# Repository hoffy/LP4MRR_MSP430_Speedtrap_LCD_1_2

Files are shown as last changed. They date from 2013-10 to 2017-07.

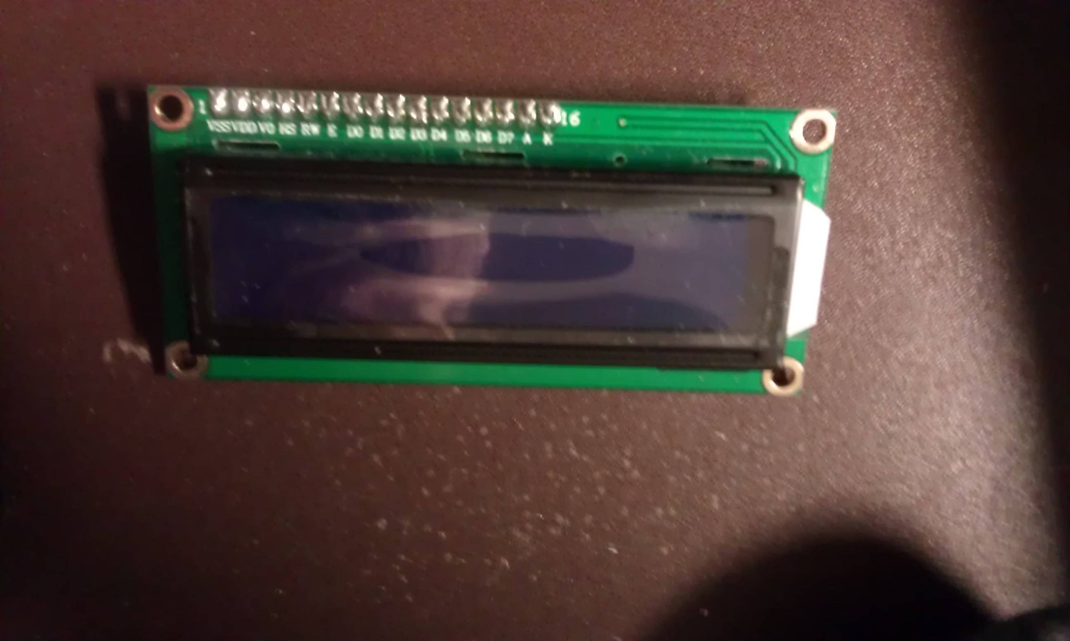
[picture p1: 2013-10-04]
1602A LCD Photo.jpg

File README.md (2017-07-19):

# LP4MRR_MSP430_Speedtrap_LCD_1_2
Code Composer Written Speed Trap with LCD for the Launchpads for Model Railroading Project

Please view the Layout Schematics & Instructions PDF

------------------------------------------------------
Revision History::

6/1/2015

I discovered recently while reviewing this repository that the schematic design had two serious "but not dangerous" issues that needed to
be corrected.  The pinout for the LCD was backwards, and a ground trace was missing on the schematic.  These issues have been resolved.
I have also included larger versions of the schematic and breadboard layouts in both PDF & PNG formats.  There is currently no Circuit
Board design associated with this project.  If anyone wishes to develop one that provides for the MSP430G2553 IC and a regulated 3.3
Volts & 5 Volt Supply as required for the circuit please by all means do so and share.  I'm all about fair attribution and open to
improvement ideas.
----------

6/5/2015

I discovered that the speed & counter variables were not clearing properly.  This was corrected by adding counter = 0 and speed = 0 to the
primary WHILE loop.  This error resulted in a miscalculation of the speed. The LCD code was also relocated to speed the processing of the
counter and reduce program lag time.
----------

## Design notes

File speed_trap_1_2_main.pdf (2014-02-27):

1 | /*
2 | * IR Beam Detected Speed Trap (Single Track Version) Version 1.2 LCD Edition
3 | *
4 | * Provided under a Creative Commons Attribution, Non-Commercial Share Alike,3.0 Unported
License
5 | *
6 | * COPYRIGHT 2013 - S.D. "Hoffy" Hofmeister, et al
7 | ********************************************************************************************
*****
8 | * CREDITS:
9 | *
10 | * Speed calculations & initial concept coding by: Toni Ryan
11 | *
12 | * IR Beam Detection & LCD Integration by: S.D. "Hoffy" Hofmeister
13 | *
14 | * LCD Library (lcdLib.h & lcdLib.c) The University of Texas at El Paso -
15 | * College of Engineering: http://www.ece.utep.edu/courses/web3376/Lab_5_-_LCD.html
16 | * Elliott Gurrola, Luis Carlos Bañuelos-Chacon, Elias N Jaquez
17 | *
18 | * This code is a group source project through The Launchpad for Model Railroading Project
19 | * - http://launchpad4mrr.blogspot.com/
20 | *
21 | ********************************************************************************************
******************
22 | * TARGETED TO MSP430 LANUCHPAD W/MSP430G2553 PROCESSOR
23 | *
24 | * Design Notes:
25 | *
26 | * This code is designed to to trigger a speed calculation for a model train passing
through 2 IR beam Sensors.
27 | * The code is designed to take a "speed reading" or "Time Count" in both directions.
28 | *
29 | * Distance between Tip of IR Emitter and Tip of Detector has only been tested up to 3.5
Inches under
30 | * incandescent and fluorescent lighting conditions with no failures.
31 | *
32 | * LCD Coding is designed for a QC1602A Ver 2.0 LCD Module
33 | *
34 | * Circuit Pinout:
35 | * PIN 1.0 = RED INDICATOR LED
36 | * PIN 1.1 = UNASSIGNED - UART
37 | * PIN 1.2 = UNASSIGNED - UART
38 | * PIN 1.3 = UNASSIGNED
39 | * PIN 1.4 = Cathode of IR Beam Receiver #1 | > Anode to Ground
40 | * PIN 1.5 = Cathode of IR Beam #2 | | > Anode to Ground
41 | * PIN 1.6 = GREEN INDICATOR LED
42 | * PIN 1.7 = UNASSIGNED
43 | * PIN 2.0 = LCD D4
44 | * PIN 2.1 = LCD D5
45 | * PIN 2.2 = LCD D6
46 | * PIN 2.3 = LCD D7
47 | * PIN 2.4 = E (Enable)
48 | * PIN 2.5 = RS (Register Signal)
49 | *
50 | * PINS 1.1, 1.2, 1.5, 1.7 are left open for integration into other projects
51 | *
52 | * Note Anodes for the IR Emitters connect to VCC and Cathodes to Ground
53 | */
54 | //******************************************************************************************
***********
55 | #include <msp430g2553.h>
56 | #include "lcdLib.h"
57 | // Declare functions
58 | void | | delay | | ( | | unsigned | | int | | ); | | // delay for xx 10ms increments
59 | // Declare variables
60 | float | | scale | | = | | 160; | | | | // denominator of scale (N scale 1:160)
61 | float | | gate | | = | | 12; | | | | // timing gate spacing (in inches)
62 | float | | speed | | = | | 0; | | // speed in MPH
63 | long | | unsigned | | int | | factor | | = | | 109090; | | | // number of ms to travel "gate" inches at 1 MPH for
"scale" scale (1 MPH slowest speed we can display)
64 | long | | unsigned | | int | | counter | | = | | 0; | | | // millisecond counter
65 | int | | counter_active | | = | | 0; | | | // flag to increment counters or stop counting
66 | int | | output_count | | = | | 0; | | | // flag to display time
67 | int | | lockgate_1 | | = | | 0; | | | // Locks Gate #1 from interrupting until unlocked
68 | int | | lockgate_2 | | = | | 0; | | | // Locks Gate #2 from interrupting until unlocked
69 | void | | main(void)
70 | {
71 | | WDTCTL | | = | | WDTPW | | + | | WDTHOLD; | | | // Stop WDT
72 | | BCSCTL1 | | = | | CALBC1_1MHZ; | | | // Set range
73 | | DCOCTL | | = | | CALDCO_1MHZ; | | | // Set DCO step + modulation
74 | | CCTL0 | | = | | CCIE; | | | // CCR0 interrupt enabled
75 | | TACTL | | = | | TASSEL_2 | | + | | MC_1 | | + | | ID_3; | // SMCLK/8, upmode
76 | | CCR0 | | = | | 125; | | | | | | | | | // 1000 Hz = 1 ms clock
77

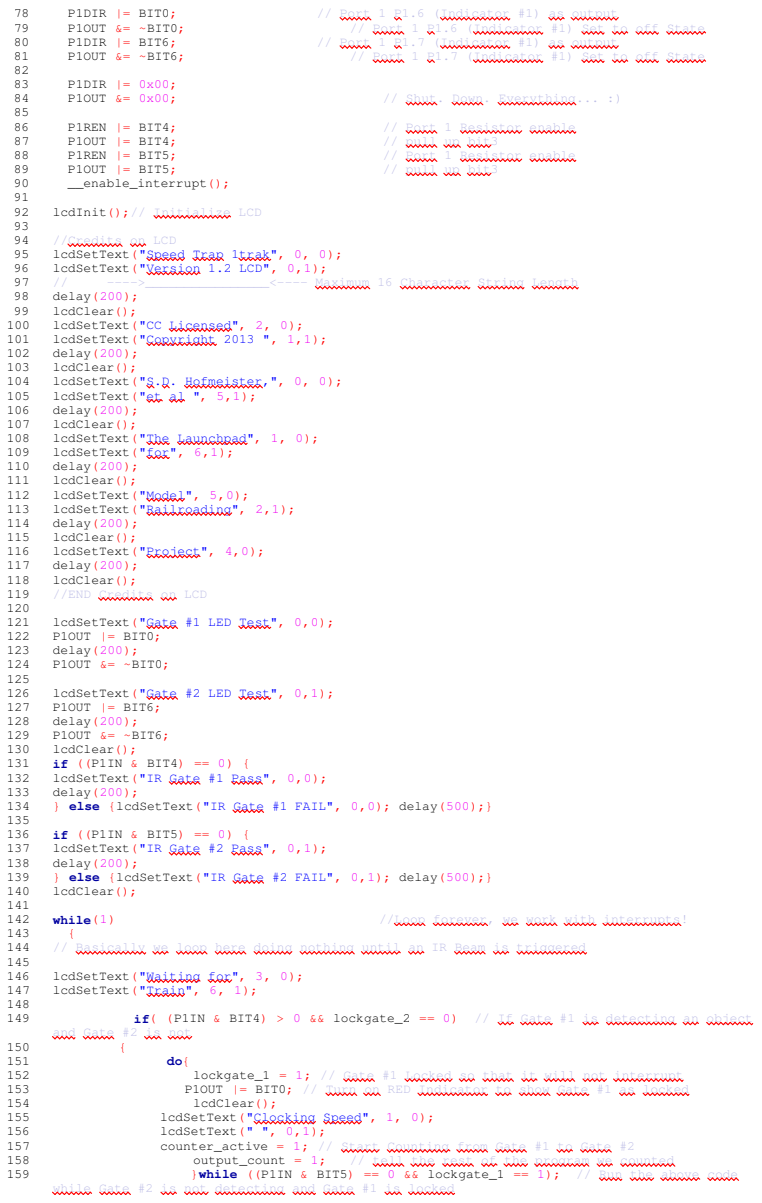
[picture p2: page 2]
P1DIR; BIT0;; // Port 1 P1.6 (Indicator #1) as output; ---->________________<---- Maximum 16 Character String Length

79 | | P1OUT | &= | ~BIT0; | | | | // Port 1 P1.6 (Indicator #1) Set to off State
80 | | P1DIR | |= | BIT6; | | | // Port 1 P1.7 (Indicator #1) as output
81 | | P1OUT | &= | ~BIT6; | | | | // Port 1 P1.7 (Indicator #1) Set to off State
82
83 | | P1DIR | |= | 0x00;
84 | | P1OUT | &= | 0x00; | | // Shut. Down. Everything... :)
85
86 | | P1REN | |= | BIT4; | | | | // Port 1 Resistor enable
87 | | P1OUT | |= | BIT4; | | | | // pull up bit3
88 | | P1REN | |= | BIT5; | | | | // Port 1 Resistor enable
89 | | P1OUT | |= | BIT5; | | | | // pull up bit3
90 | | __enable_interrupt();
91
92 | lcdInit();// Initialize LCD
93
94 | //Credits on LCD
95 | lcdSetText("Speed Trap 1trak", | | | 0, | 0);
96 | lcdSetText("Version 1.2 LCD", | | | 0,1);

98 | delay(200);
99 | lcdClear();
100 | lcdSetText("CC Licensed", | | | | | 2, | | | 0);
101 | lcdSetText("Copyright 2013 ", | | | | | 1,1);
102 | delay(200);
103 | lcdClear();
104 | lcdSetText("S.D. Hofmeister,", | | | | | 0, | | | 0);
105 | lcdSetText("et al ", | | | | | 5,1);
106 | delay(200);
107 | lcdClear();
108 | lcdSetText("The Launchpad", | | | | | 1, | | | 0);
109 | lcdSetText("for", | | | | | 6,1);
110 | delay(200);
111 | lcdClear();
112 | lcdSetText("Model", | | | | | 5,0);
113 | lcdSetText("Railroading", | | | | | 2,1);
114 | delay(200);
115 | lcdClear();
116 | lcdSetText("Project", | | | | | 4,0);
117 | delay(200);
118 | lcdClear();
119 | //END Credits on LCD
120
121 | lcdSetText("Gate #1 LED Test", | | | | | 0,0);
122 | P1OUT | | |= | | BIT0;
123 | delay(200);
124 | P1OUT | | &= | | ~BIT0;
125
126 | lcdSetText("Gate #2 LED Test", | | | | | 0,1);
127 | P1OUT | | |= | | BIT6;
128 | delay(200);
129 | P1OUT | | &= | | ~BIT6;
130 | lcdClear();
131 | if | | ((P1IN | | | & | | BIT4) | | | == | | 0) | | | {
132 | lcdSetText("IR Gate #1 Pass", | | | | | 0,0);
133 | delay(200);
134 | } | | else | | {lcdSetText("IR Gate #1 FAIL", | | | | | | 0,0); | | | | | delay(500);}
135
136 | if | | ((P1IN | | | & | | BIT5) | | | == | | 0) | | | {
137 | lcdSetText("IR Gate #2 Pass", | | | | | 0,1);
138 | delay(200);
139 | } | | else | | {lcdSetText("IR Gate #2 FAIL", | | | | | | 0,1); | | | | | delay(500);}
140 | lcdClear();
141
142 | while(1) | | | | | //Loop forever, we work with interrupts!
143 | | {
144 | // Basically we loop here doing nothing until an IR Beam is triggered
145
146 | lcdSetText("Waiting for", | | | | | 3, | | | 0);
147 | lcdSetText("Train", | | | | | 6, | | | 1);
148
149 | | | | if( | | | (P1IN | | | & | | BIT4) | | | > | | 0 | | && | | lockgate_2 | | == | | 0) | | // If Gate #1 is detecting an object

and Gate #2 is not

150 | | {
151 | | | | | do{
152 | | | | | | | lockgate_1 | | = | | 1; | | | // Gate #1 Locked so that it will not interrupt
153 | | | | | | P1OUT | | |= | | BIT0; | | | // Turn on RED Indicator to show Gate #1 as locked
154 | | | | | | | lcdClear();
155 | | | | lcdSetText("Clocking Speed", | | | | | 1, | | | 0);
156 | | | | lcdSetText(" ", | | | | | 0,1);
157 | | | | counter_active | | = | | 1; | | | // Start Counting from Gate #1 to Gate #2
158 | | | | | | | output_count | | = | | 1; | | | | // tell the rest of the program we counted
159 | | | | | }while | | | ((P1IN | | | & | | BIT5) | | | == | | 0 | | && | | lockgate_1 | | == | | 1); | | // Run the above code

while Gate #2 is not detecting and Gate #1 is locked

160 | } | else | {lockgate_1 | = | 0; | P1OUT | &= | ~BIT0;} | // Otherwise unlock Gate #1 and turn off
RED INDICATOR LED
161
162
163
164 | | if( | | | (P1IN | | | & | | BIT5) | | | > | | 0 | | && | | lockgate_1 | == | | 0 | ) | // If Gate #2 is detecting an object
and Gate #1 is not
165 | | {
166 | | | do | | {
167 | | | | lockgate_2 | | = | | 1; | | | // Gate #2 Locked so that it will not interrupt
168 | | | | P1OUT | | |= | | BIT6; | | | // Turn on GREEN Indicator to show Gate #2 as locked
169 | | | | lcdClear();
170 | | | | lcdSetText("Clocking Speed", | | | | | 1, | | | 0);
171 | | | | lcdSetText(" ", | | | | | 0,1);
172 | | | | counter_active | | = | | 1; | | | // Start Counting from Gate #2 to Gate #1
173 | | | | output_count | | = | | 1; | | | // tell the rest of the program we counted
174 | | | | }while | | | ((P1IN | | | & | | BIT4) | | | == | | 0 | | && | lockgate_2 | | == | 1); | | // Run the above code
while Gate #1 is not detecting and Gate #2 is locked
175
176 | | | }else | | | {lockgate_2 | | | = | | 0; | | | P1OUT | | &= | | ~BIT6;} | | | // Otherwise unlock Gate #2 and turn
off GREEN INDICATOR LED
177
178 | | counter_active | | = | | 0; | | | | // done counting - ready to output
179
180 | | | | if | | ( | | output_count | | == | | 1 | | ) | | { | | // show the count
181 | | | | | // calculate speed in MPH
182 | | | | | speed | | = | | factor | | / | | counter; | | | // calculate MPH
183 | | | | | lcdClear();
184 | | | | | lcdSetText("Train Speed", | | | | | 2, | | | 0);
185 | | | | | lcdSetInt(speed, | | | | | 4, | | | 1);
186 | | | | | lcdSetText("MPH", | | | | | 8,1);
187 | | | | | delay(500);
188 | | | | | output_count | | = | | 0; | | | // stop displaying and wait for another trigger
189 | | | | | lcdClear();
190
191 | | | } | | | // end of IF
192 | | } | | | // end of WHILE
193 | } | | | // end of MAIN
194
195 | // Timer A0 interrupt service routine
196 | #pragma vector=TIMER0_A0_VECTOR
197 | __interrupt | | void | | Timer_A | | (void)
198 | {
199 | | if | | (counter_active | | | == | | 1) | | | {
200 | | | counter | | = | | counter | | + | | 1; | | | | // just counting milliseconds
201
202 | | | if | | (counter | | | > | | factor) | | | { | | | // if our counter reaches factor, we're going less than
1 MPH
203 | | | | | | | | | | // and we can't display it, so ...
204 | | | | counter | | = | | 0; | | | | | | // zero counter
205 | | | | counter_active | | = | | 0; | | | | // stop counting
206 | | | | delay(1000); | | | | | | // and hang for a bit
207 | | | | }
208 | | }// then return to main
209 | }// end of TIMER_A interrupt handler
210
211 | // Port 1 interrupt service routine
212 | #pragma vector=PORT1_VECTOR
213 | __interrupt | | void | | Port_1(void)
214 | {
215 | | while | | (lockgate_1 | | | == | | 1) | | | { | | // Locks interrupt from disturbing opposite direction
| detection
216 | | | P1IFG | | &= | | ~BIT5; | | | | | | // P1.4 IFG cleared
217 | | | P1IES | | ^= | | BIT5; | | | // toggle the interrupt edge,
218 | | }
219
220 | | while | | (lockgate_2 | | | == | | 1) | | | { | | // Locks interrupt from disturbing opposite direction
| detection
221 | | | P1IFG | | &= | | ~BIT4; | | | | | | // P1.5 IFG cleared
222 | | | P1IES | | ^= | | BIT4; | | | // toggle the interrupt edge,
223 | | }
224 | | | // the interrupt vector will be called
225 | | | // when P1.4 or P1.5 goes from HitoLow as well as
226 | | | // LowtoHigh
227 | }
228
229 | void | | delay(unsigned | | | | int | | ms) | | | // delay for ms in 10 millisecond intervals
230 | {
231 | | while | | (ms--)
232 | | {
233 | | __delay_cycles(10000); | | | | | // set for 1 Mhz (10000=10ms)
234 | | }
235 | }
236

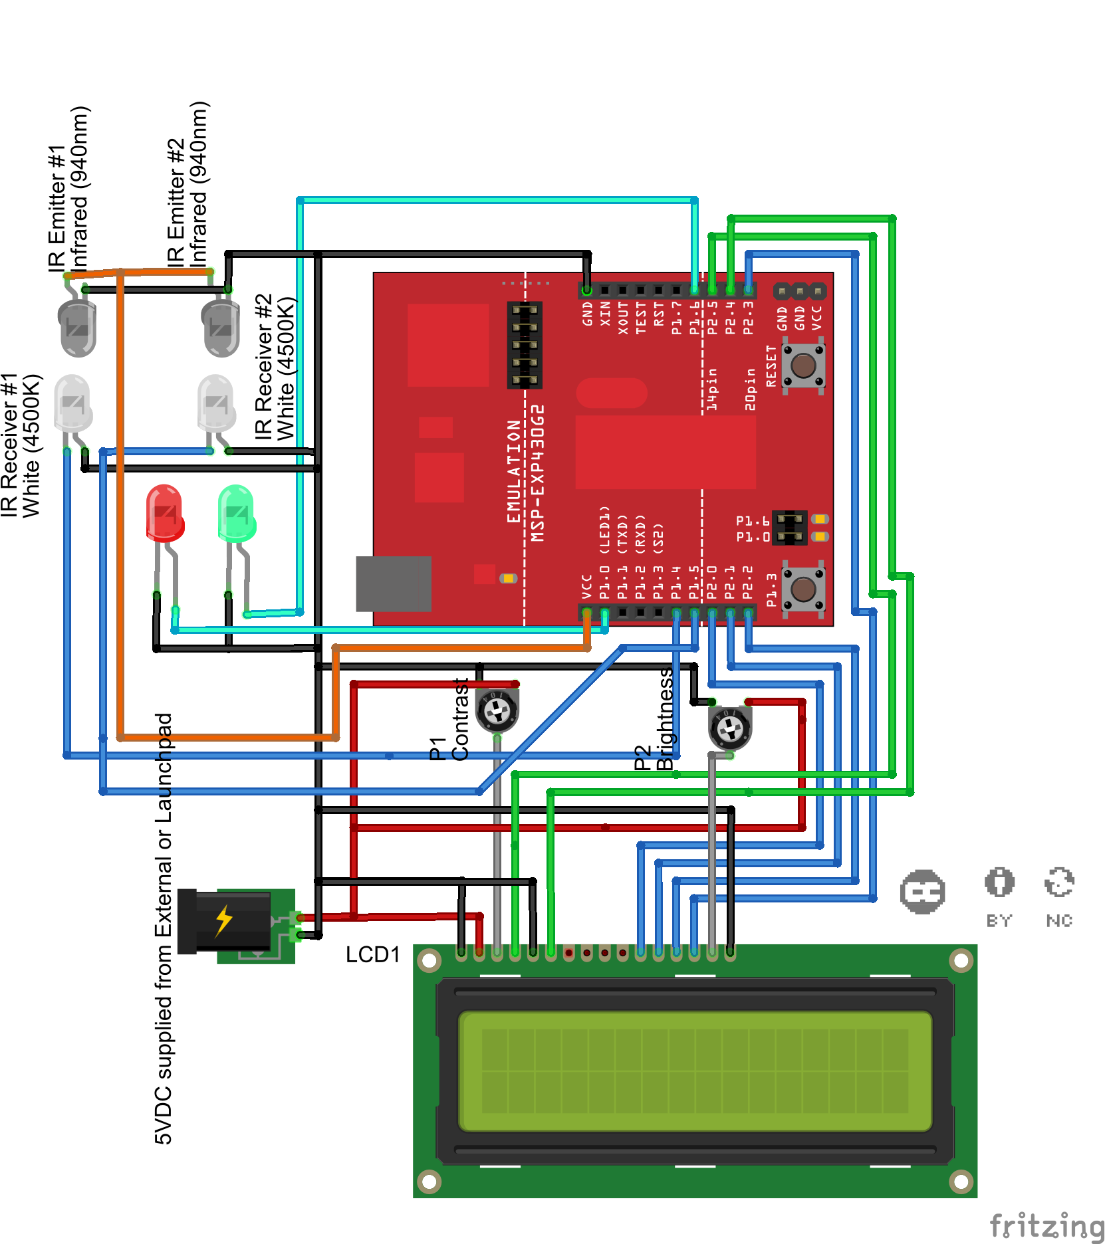
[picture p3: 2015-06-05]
Speedtrap LCD EDITION- revised_bb.png

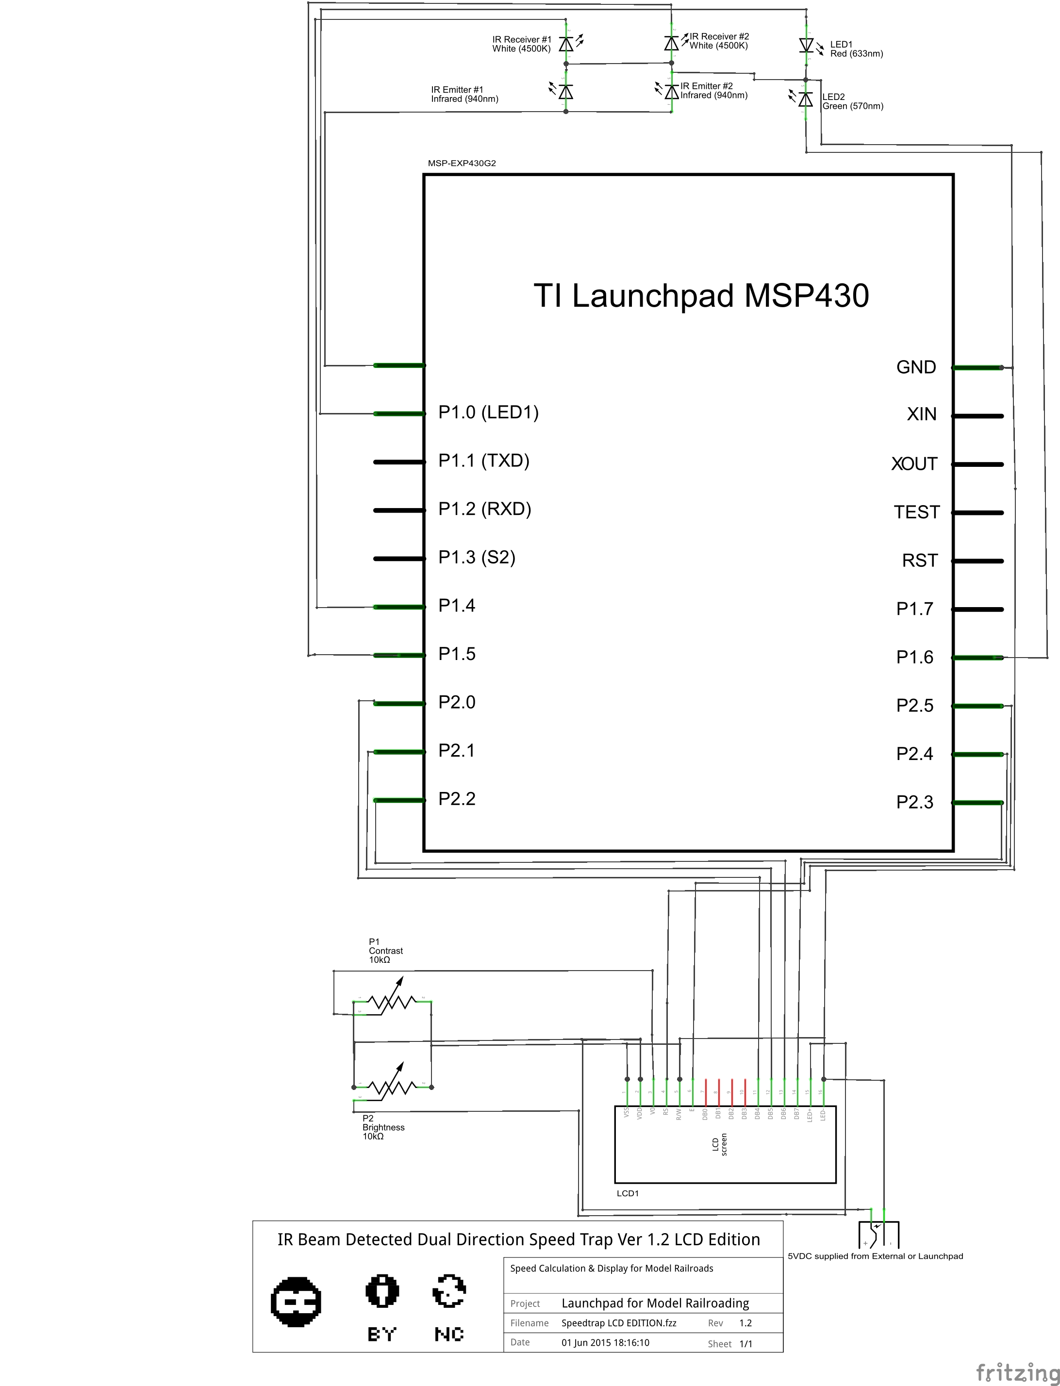
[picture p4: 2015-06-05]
Speedtrap LCD EDITION- revised_schem.png

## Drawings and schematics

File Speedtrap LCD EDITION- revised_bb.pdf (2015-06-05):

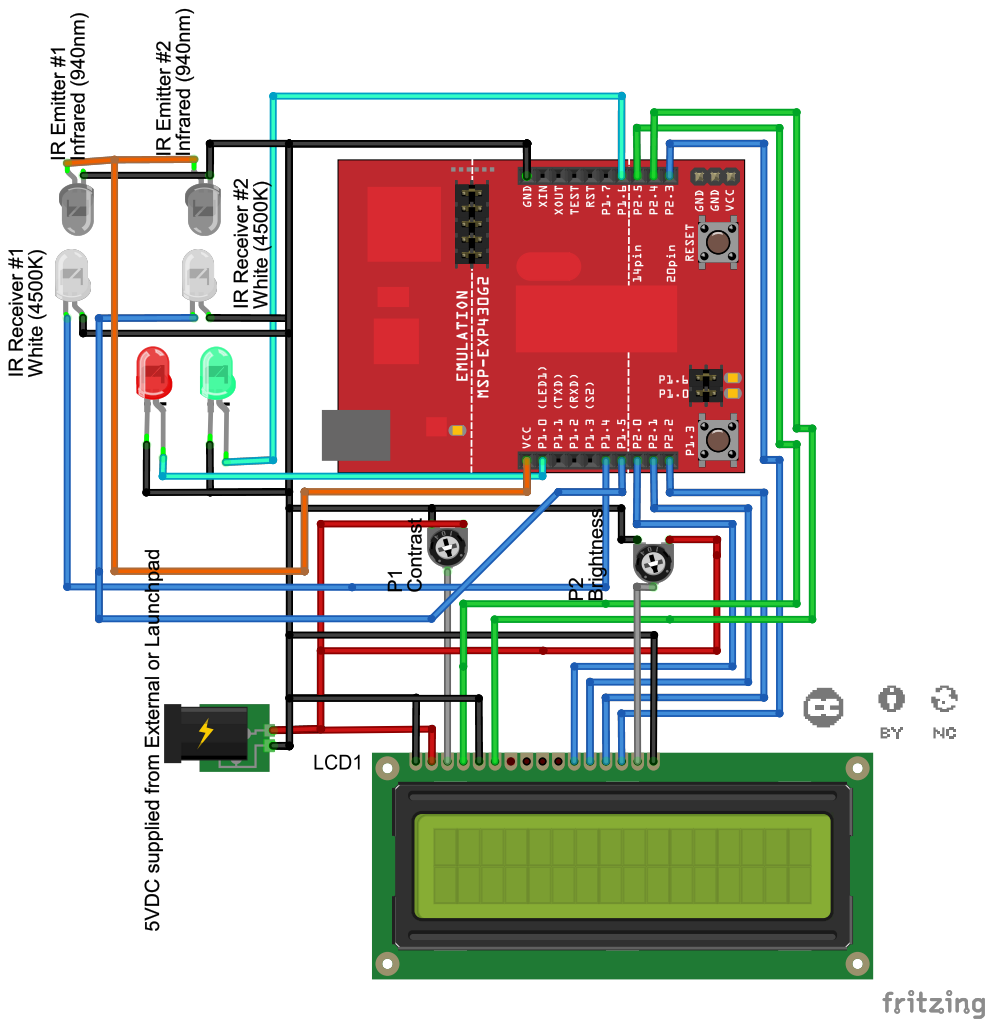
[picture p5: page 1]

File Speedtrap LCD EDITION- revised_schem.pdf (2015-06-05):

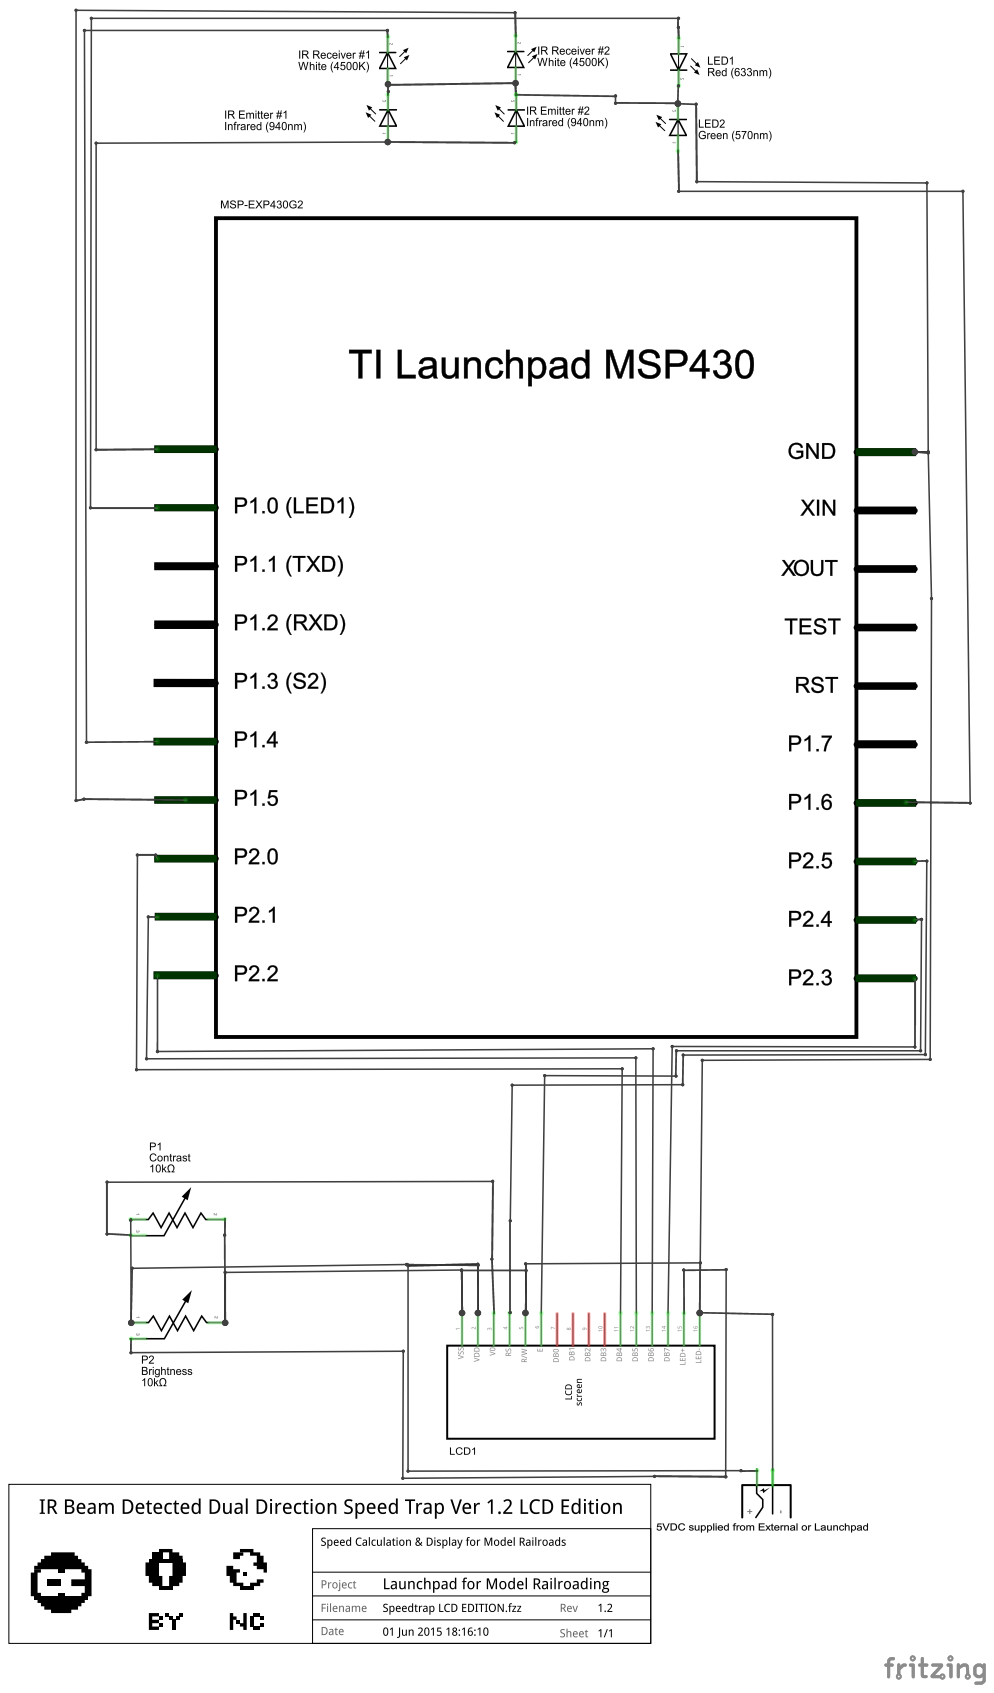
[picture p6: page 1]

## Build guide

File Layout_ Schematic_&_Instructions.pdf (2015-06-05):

Project Layout & Schematic – IR Beam Detected Dual Direction Speed Trap Ver. 1.2 LCD Edition

### Schematic Revised 6/1/2015

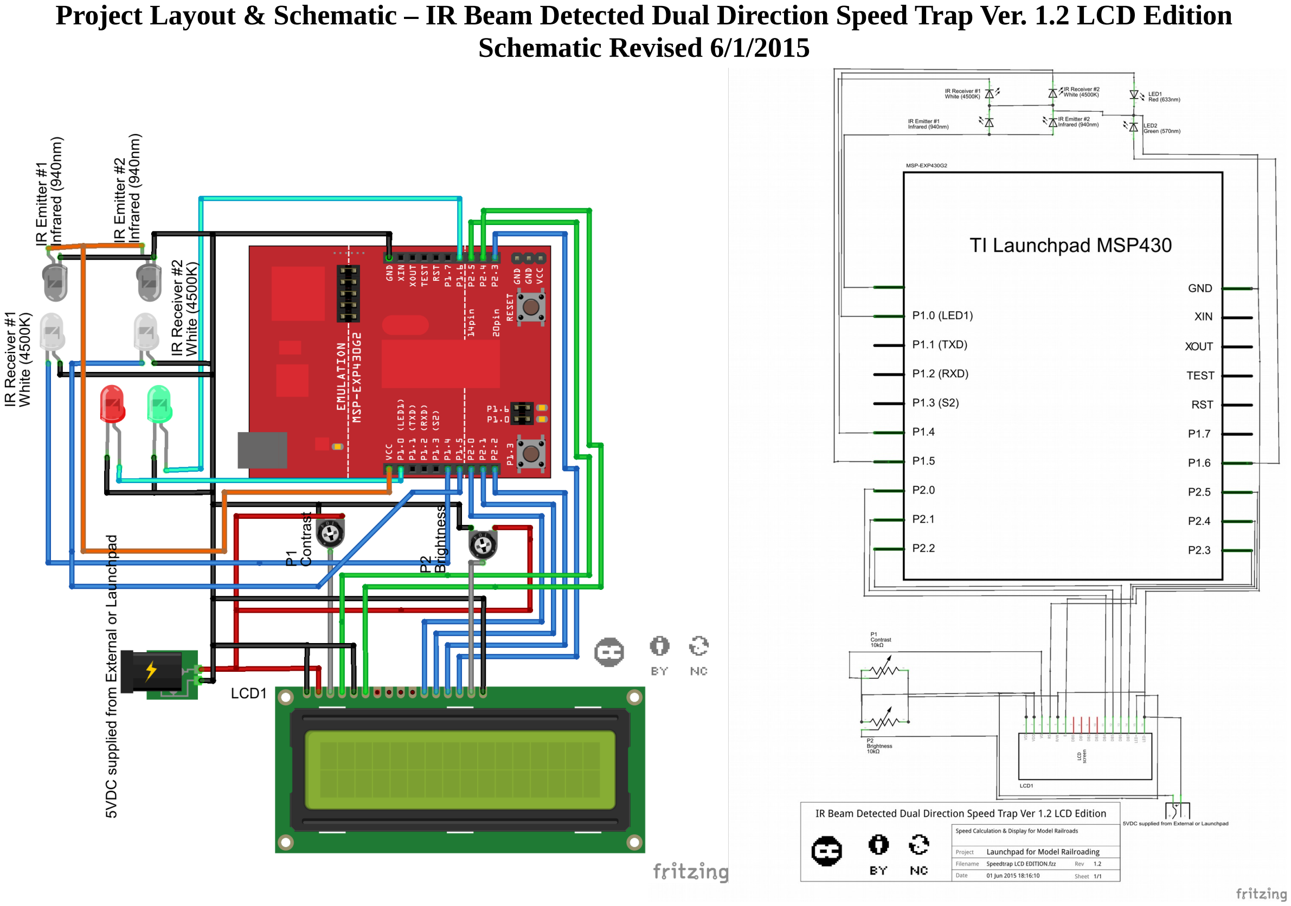
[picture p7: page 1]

**** TAKE CAREFUL NOTE: The IR receivers connect to ground differently than the emitters **** IR Beam Detected Speed Trap (Single Track Version) Version 1.2 LCD Edition
COPYRIGHT 2013 - S.D. "Hoffy" Hofmeister, et al
CREDITS:
Speed calculations & initial concept coding by: Toni Ryan
IR Beam Detection & LCD Integration by: S.D. "Hoffy" Hofmeister
LCD Library (lcdLib.h & lcdLib.c) The University of Texas at El Paso -
College of Engineering: http://www.ece.utep.edu/courses/web3376/Lab_5_-_LCD.html Elliott Gurrola, Luis Carlos Bañuelos-Chacon, Elias N Jaquez
This code is a group source project through The Launchpad for Model Railroading Project
- http://launchpad4mrr.blogspot.com/
TARGETED TO MSP430 LANUCHPAD W/MSP430G2553 PROCESSOR
Design Notes:
This code is designed to to trigger a speed calculation for a model train passing through 2 IR beam Sensors. The code is designed to take a "speed reading" or "Time Count" in both directions.
Distance between Tip of IR Emitter and Tip of Detector has only been tested up to 3.5 Inches under incandescent and fluorescent lighting conditions with no failures.
LCD Coding is designed for a QC1602A Ver 2.0 LCD Module
A Data sheet for the LCD is contained within this package. An equivalent 3.3V display can be used instead, but
was unavailable to me at the time of this projects development.
Circuit Pinout:
PIN 1.0 = RED INDICATOR LED
PIN 1.1 = UNASSIGNED - UART
PIN 1.2 = UNASSIGNED - UART
PIN 1.3 = UNASSIGNED
PIN 1.4 = Cathode of IR Beam Receiver #1 > Anode to Ground PIN 1.5 = Cathode of IR Beam #2> Anode to Ground
PIN 1.6 = GREEN INDICATOR LED
PIN 1.7 = UNASSIGNED
PIN 2.0 = LCD D4
PIN 2.1 = LCD D5
PIN 2.2 = LCD D6
PIN 2.3 = LCD D7
PIN 2.4 = E (Enable)
PIN 2.5 = RS (Register Signal)
Installation of Code Project:
This package contains a Code Composer Studio Ver. 5 Export. This project contains additional files and header files which must compile along with the code itself in order for the LCD to work.

Follow the instructions on importing a project in Code Composer Studio.

Parts List:

Qty Description
1 LCD 16 Character 2 line Display 1602A – an equivalent to the one used in my prototype can be found at https://www.sparkfun.com/products/709 however search the internet for 1602A 16x2 LCD may turn up better deals.
Mine were acquired through eBay rather cheap.

### 2 Infrared LED Emitters

These can be found on ebay, and in some hobby shops

### 2 Infrared Detectors

These can be found on ebay, and in some hobby shops
2 10K Ohm Potentiometers
http://www.mouser.com/ProductDetail/Bourns/3306F-1-103/?qs=sGAEpiMZZMtC25l1F4XBU9QhtPcWQTANAkX0QUL%2f5Dw%3d Optionals
RED LED There are a Red & Green LED built on board the MSP430G2 Board. This project shows them externally for GREEN LED demonstration purposes.

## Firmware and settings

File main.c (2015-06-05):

/*
* IR Beam Detected Speed Trap (Single Track Version - Dual Direction) Version 1.3 LCD Edition
*
* Provided under a Creative Commons Attribution, Non-Commercial Share Alike,4.0 Unported License
*
* COPYRIGHT 2015 - S.D. "Hoffy" Hofmeister, et al
*************************************************************************************************
* CREDITS:
*
* Speed calculations & initial concept coding by: Toni Ryan
*
* IR Beam Detection & LCD Integration by: S.D. "Hoffy" Hofmeister
*
* LCD Library (lcdLib.h & lcdLib.c) The University of Texas at El Paso -
* College of Engineering: http://www.ece.utep.edu/courses/web3376/Lab_5_-_LCD.html
* Elliott Gurrola, Luis Carlos Bañuelos-Chacon, Elias N Jaquez
*
* This code is a group source project through The Launchpad for Model Railroading Project
* - http://launchpad4mrr.blogspot.com/
*
**************************************************************************************************************
* TARGETED TO MSP430 LANUCHPAD W/MSP430G2553 PROCESSOR
*
* Design Notes:
*
* This code is designed to to trigger a speed calculation for a model train passing through 2 IR beam Sensors.
* The code is designed to take a "speed reading" or "Time Count" in both directions.
*
* Distance between Tip of IR Emitter and Tip of Detector has only been tested up to 3.5 Inches under
* incandescent and fluorescent lighting conditions with no failures.
*
* LCD Coding is designed for a QC1602A Ver 2.0 LCD Module
*
* Circuit Pinout:
* PIN 1.0 = RED INDICATOR LED
* PIN 1.1 = UNASSIGNED - UART
* PIN 1.2 = UNASSIGNED - UART
* PIN 1.3 = UNASSIGNED
* PIN 1.4 = Cathode of IR Beam Receiver #1	> Anode to Ground
* PIN 1.5 = Cathode of IR Beam #2	> Anode to Ground
* PIN 1.6 = GREEN INDICATOR LED
* PIN 1.7 = UNASSIGNED
* PIN 2.0 = LCD D4
* PIN 2.1 = LCD D5
* PIN 2.2 = LCD D6
* PIN 2.3 = LCD D7
* PIN 2.4 = E (Enable)
* PIN 2.5 = RS (Register Signal)
*
* PINS 1.1, 1.2, 1.5, 1.7 are left open for integration into other projects
*
* Note Anodes for the IR Emitters connect to VCC and Cathodes to Ground
*/
//*****************************************************************************************************
#include <msp430g2553.h>
#include "lcdLib.h"
// Declare functions
void delay ( unsigned int );	// delay for xx 10ms increments
// Declare variables
float scale = 160; 	// denominator of scale (N scale 1:160)
float gate = 12; 	// timing gate spacing (in inches)
float speed = 0;	// speed in MPH
long unsigned int factor = 109090;	// number of ms to travel "gate" inches at 1 MPH for "scale" scale (1 MPH slowest speed we can display)
long unsigned int counter = 0;	// millisecond counter
int counter_active = 0; // flag to increment counters or stop counting
int output_count = 0;	// flag to display time
int lockgate_1 = 0;  // Locks Gate #1 from interrupting until unlocked
int lockgate_2 = 0; // Locks Gate #2 from interrupting until unlocked
void main(void)
{
  WDTCTL = WDTPW + WDTHOLD;                 // Stop WDT
  BCSCTL1 = CALBC1_1MHZ; // Set range
  DCOCTL = CALDCO_1MHZ; // Set DCO step + modulation
  CCTL0 = CCIE;                             // CCR0 interrupt enabled
  TACTL = TASSEL_2 + MC_1 + ID_3;           // SMCLK/8, upmode
  CCR0 =  125; 								// 1000 Hz = 1 ms clock

  P1DIR |= BIT0;					// Port 1 P1.6 (Indicator #1) as output
  P1OUT &= ~BIT0;					// Port 1 P1.6 (Indicator #1) Set to off State
  P1DIR |= BIT6;					// Port 1 P1.7 (Indicator #1) as output
  P1OUT &= ~BIT6;					// Port 1 P1.7 (Indicator #1) Set to off State

  P1DIR |= 0x00;
  P1OUT &= 0x00;                        	// Shut. Down. Everything... :)

  P1REN |= BIT4;							// Port 1 Resistor enable
  P1OUT |= BIT4;							// pull up bit3
  P1REN |= BIT5;							// Port 1 Resistor enable
  P1OUT |= BIT5;							// pull up bit3
  __enable_interrupt();

lcdInit();// Initialize LCD

//Credits on LCD
lcdSetText("Speed Trap Single", 0, 0);
lcdSetText("Version 1.3 LCD", 0,1);
//     ---->________________<---- Maximum 16 Character String Length
delay(200);
lcdClear();
lcdSetText("CC Licensed", 2, 0);
lcdSetText("Copyright 2015 ", 1,1);
delay(200);
lcdClear();
lcdSetText("S.D. Hofmeister,", 0, 0);
lcdSetText("et al ", 5,1);
delay(200);
lcdClear();
lcdSetText("The Launchpad", 1, 0);
lcdSetText("for", 6,1);
delay(200);
lcdClear();
lcdSetText("Model", 5,0);
lcdSetText("Railroading", 2,1);
delay(200);
lcdClear();
lcdSetText("Project", 4,0);
delay(200);
lcdClear();
//END Credits on LCD

lcdSetText("Gate #1 LED Test", 0,0);
P1OUT |= BIT0;
delay(200);
P1OUT &= ~BIT0;

lcdSetText("Gate #2 LED Test", 0,1);
P1OUT |= BIT6;
delay(200);
P1OUT &= ~BIT6;
lcdClear();
if ((P1IN & BIT4) == 0) {
lcdSetText("IR Gate #1 Pass", 0,0);
delay(200);
} else {lcdSetText("IR Gate #1 FAIL", 0,0); delay(500);}

if ((P1IN & BIT5) == 0) {
lcdSetText("IR Gate #2 Pass", 0,1);
delay(200);
} else {lcdSetText("IR Gate #2 FAIL", 0,1); delay(500);}
lcdClear();

while(1)                                  //Loop forever, we work with interrupts!
  {
// Basically we loop here doing nothing until an IR Beam is triggered
speed = 0;
counter = 0;
lcdSetText("Waiting for", 3, 0);
lcdSetText("Train", 6, 1);

		  if( (P1IN & BIT4) > 0 && lockgate_2 == 0)  // If Gate #1 is detecting an object and Gate #2 is not
        	{ lcdClear();
   		      lcdSetText("Clocking Speed", 1, 0);
   		      lcdSetText(" ", 0,1);
			  do{
			  	lockgate_1 = 1; // Gate #1 Locked so that it will not interrupt
			  	P1OUT |= BIT0; // Turn on RED Indicator to show Gate #1 as locked

        		 counter_active = 1; // Start Counting from Gate #1 to Gate #2
  				 output_count = 1; 	// tell the rest of the program we counted
			     }while ((P1IN & BIT5) == 0 && lockgate_1 == 1);  // Run the above code while Gate #2 is not detecting and Gate #1 is locked
        	} else {lockgate_1 = 0; P1OUT &= ~BIT0; } // Otherwise unlock Gate #1 and turn off RED INDICATOR LED



          if( (P1IN & BIT5) > 0 && lockgate_1 == 0 ) // If Gate #2 is detecting an object and Gate #1 is not
          { lcdClear();
		    lcdSetText("Clocking Speed", 1, 0);
		    lcdSetText(" ", 0,1);
        	  do {
        		  lockgate_2 = 1; // Gate #2 Locked so that it will not interrupt
        		  P1OUT |= BIT6; // Turn on GREEN Indicator to show Gate #2 as locked

        		  counter_active = 1; // Start Counting from Gate #2 to Gate #1
        		  output_count = 1; 	// tell the rest of the program we counted
               	 }while ((P1IN & BIT4) == 0 && lockgate_2 == 1); // Run the above code while Gate #1 is not detecting and Gate #2 is locked

          	}else {lockgate_2 = 0; P1OUT &= ~BIT6; } // Otherwise unlock Gate #2 and turn off GREEN INDICATOR LED

   counter_active = 0; 	// done counting - ready to output

  		if ( output_count == 1 ) {	// show the count
  			// calculate speed in MPH
  			speed = factor / counter;	// calculate MPH
  			lcdClear();
  			lcdSetText("Train Speed", 2, 0);
  			lcdSetInt(speed, 4, 1);
  			lcdSetText("MPH", 8,1);
  			delay(500);

  			output_count = 0;	// stop displaying and wait for another trigger

  			lcdClear();

  	} 	// end of IF
  } 	// end of WHILE
} 	// end of MAIN

// Timer A0 interrupt service routine
#pragma vector=TIMER0_A0_VECTOR
__interrupt void Timer_A (void)
{
	if (counter_active == 1) {
		counter = counter + 1; 	// just counting milliseconds

		if (counter > factor) { 	// if our counter reaches factor, we're going less than 1 MPH
									// and we can't display it, so ...
			counter = 0; 			// zero counter
			counter_active = 0;		// stop counting

			delay(1000);			// and hang for a bit
			}
	}// then return to main
}// end of TIMER_A interrupt handler

// Port 1 interrupt service routine
#pragma vector=PORT1_VECTOR
__interrupt void Port_1(void)
{
	while (lockgate_1 == 1)  {  // Locks interrupt from disturbing opposite direction detection
	   P1IFG &= ~BIT5;                     		// P1.4 IFG cleared
	   P1IES ^= BIT5; // toggle the interrupt edge,
	}

	while (lockgate_2 == 1) { // Locks interrupt from disturbing opposite direction detection
	   P1IFG &= ~BIT4;                     		// P1.5 IFG cleared
	   P1IES ^= BIT4; // toggle the interrupt edge,
	}
	   // the interrupt vector will be called
	   // when P1.4 or P1.5 goes from HitoLow as well as
	   // LowtoHigh
}

void delay(unsigned int ms)	// delay for ms in 10 millisecond intervals
{
 while (ms--)
    {
        __delay_cycles(10000); // set for 1 Mhz (10000=10ms)
    }
}

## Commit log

2013-10-04 Added Project to Repository
    Project written in Texas Instruments Code Composer Studio
    [Speedtrap LCD EDITION.fzz]
2015-06-05 Fixed Speed Calculation Error
    The Core code has been modified to correct a miscalculation of the speed
    caused by the counter and speed data not clearing properly. The LCD
    code was also relocated to speed the process of the program.
    [Speedtrap LCD EDITION- revised.fzz]
